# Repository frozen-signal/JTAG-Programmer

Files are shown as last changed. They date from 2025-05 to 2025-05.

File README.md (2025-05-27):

# Description

A Kicad project for a JTAG Programmer. Compatible with Lattice Diamond Programmer, Radiant Programmer and iCEcube2.

# How to use

## One-time setup

Once assembled, a one-time setup need to be done:
1. Download and install [FT_Prog from FTDI](https://ftdichip.com/utilities/#ft_prog)
1. Connect the JTAG-Programmer to your PC with a USB cable.
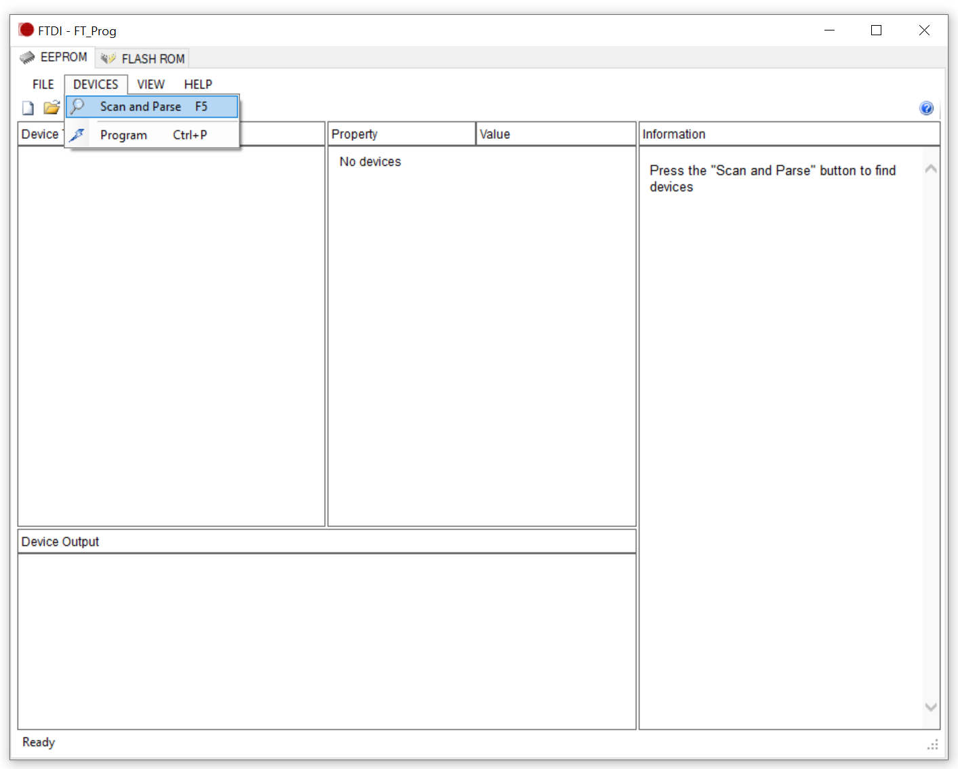
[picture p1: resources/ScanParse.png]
1. Do a scan: DEVICE > Scan and parse.<br />
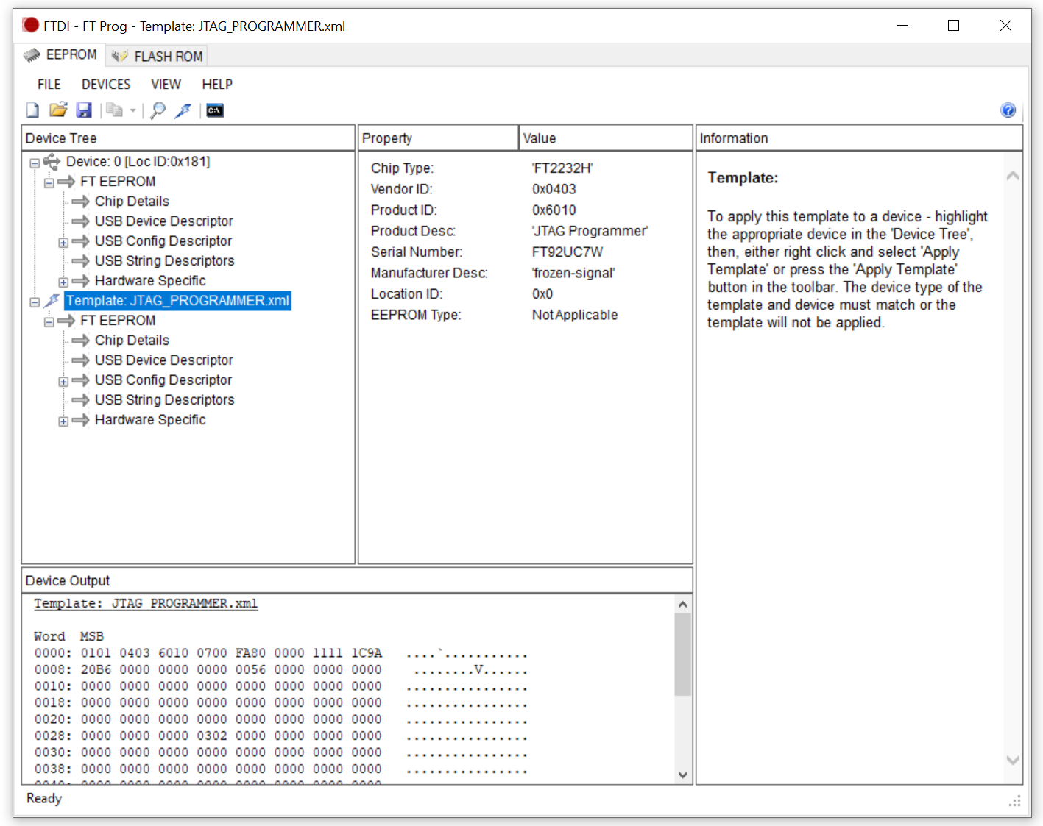
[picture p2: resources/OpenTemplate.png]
1. Go to FILE > Open Template and select "JTAG_PROGRAMMER.xml".<br />
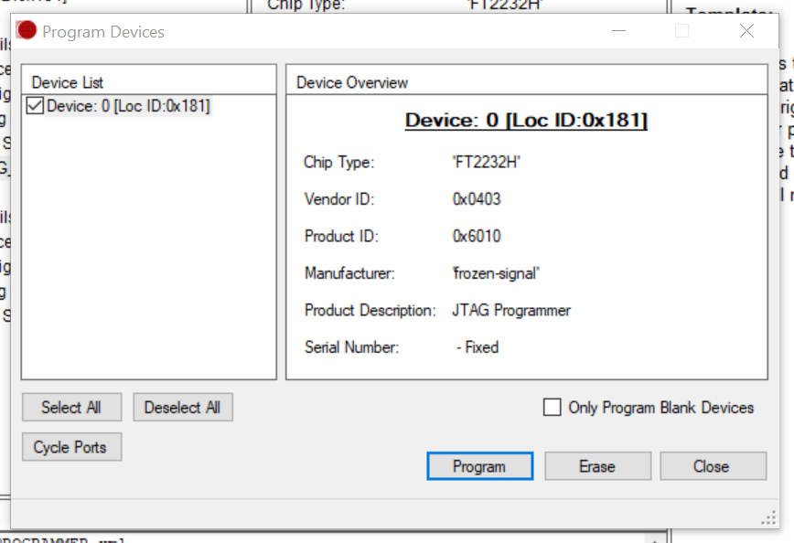
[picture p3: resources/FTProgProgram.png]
1. Go to DEVICE > Program, and click "Erase". Once completed, click "Program".<br />
1. Make sure the JTAG-Programmer has been correctly programmed by quitting FT_Prog and re-opening it, then doing a scan again. Check that the template has been applied to the JTAG-Programmer ("Product Desc" should be "JTAG Program").

## Example of Programming a MACHXO2 FPGA with Lattice Diamond Programmer

This shows an example of how the JTAG-Programmer can be used to program a FPGA. This example suppose you already have installed the Lattice Diamond Programmer (As standalone or as part of the [Lattice Diamond Toolchain](https://www.latticesemi.com/Products/DesignSoftwareAndIP/FPGAandLDS/LatticeDiamond)
1. Make sure the JTAG-Programmer is connected to the PC.
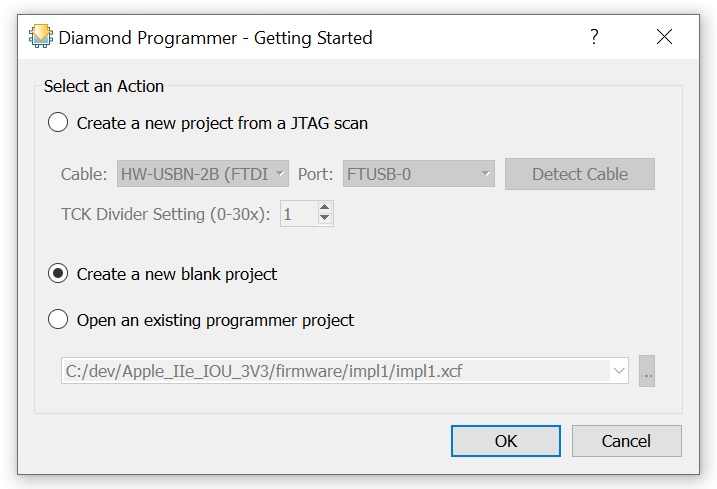
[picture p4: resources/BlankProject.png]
1. Run the Lattice Diamond Programmer, select "Create a new blank project" is selected, and click "OK".<br />
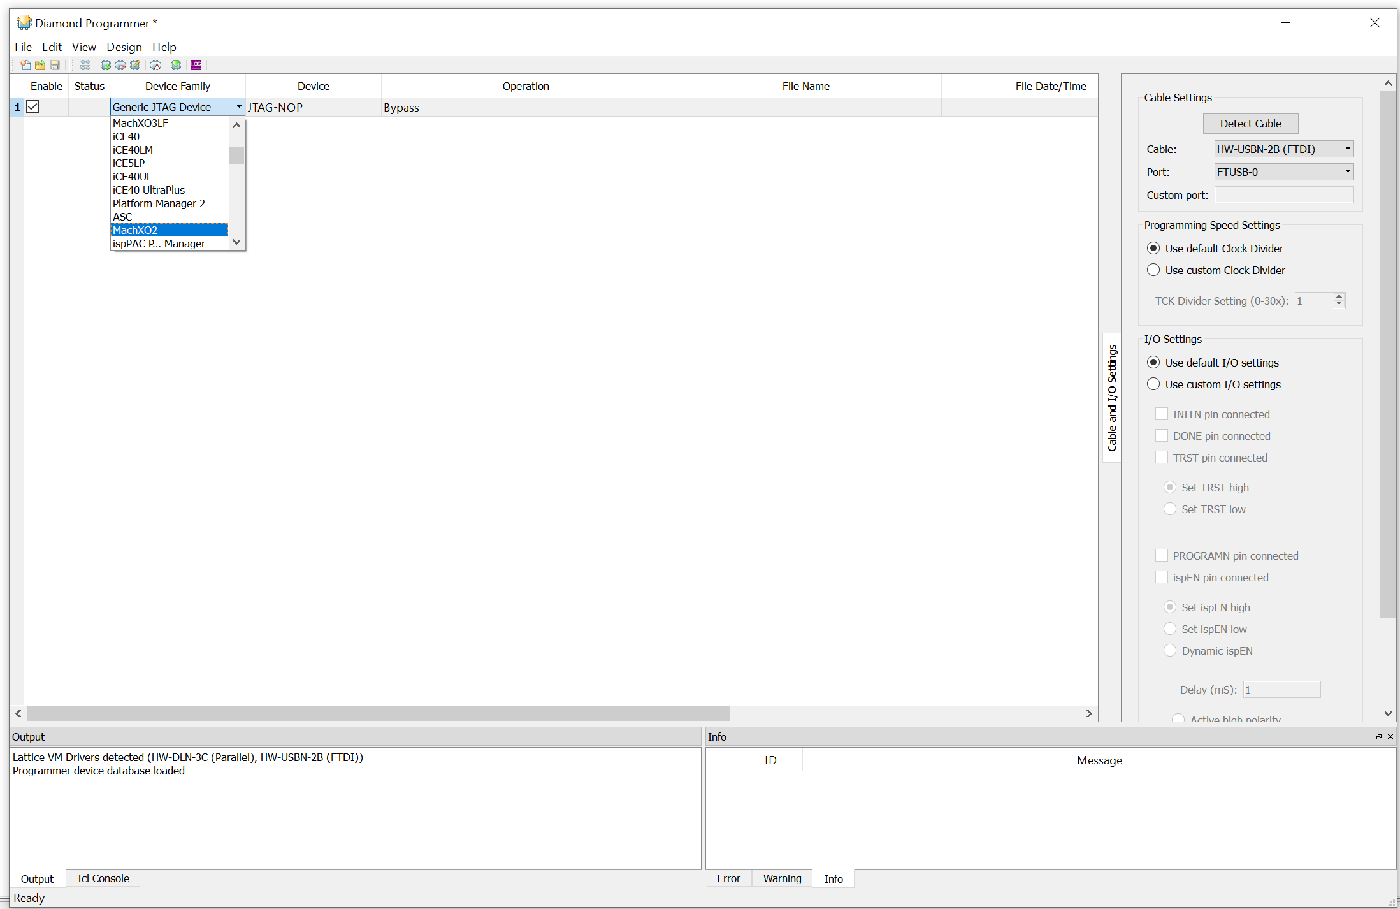
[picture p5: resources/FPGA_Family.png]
1. Click on the "Generic JTAG Device" under Device Family, and select the FPGA family.<br />
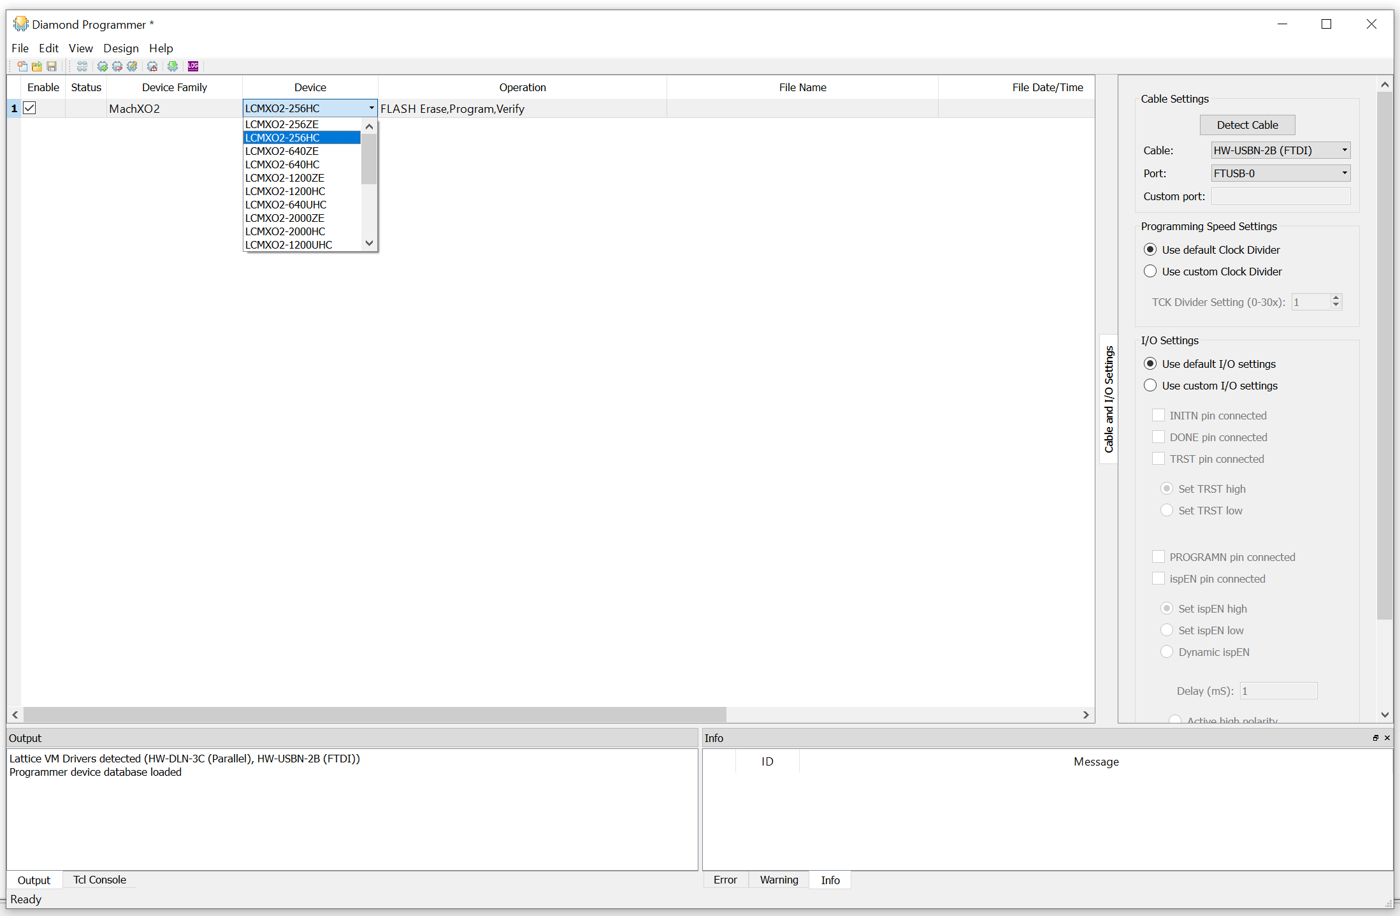
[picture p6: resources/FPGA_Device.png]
1. Click on the element under "Device" and select the correct device.<br />
1. Make sure the Operation is "Flash Erase,Program,Verify".
1. Under File Name, select the programming file. In our case, it's the generated JEDEC file (*.jed).
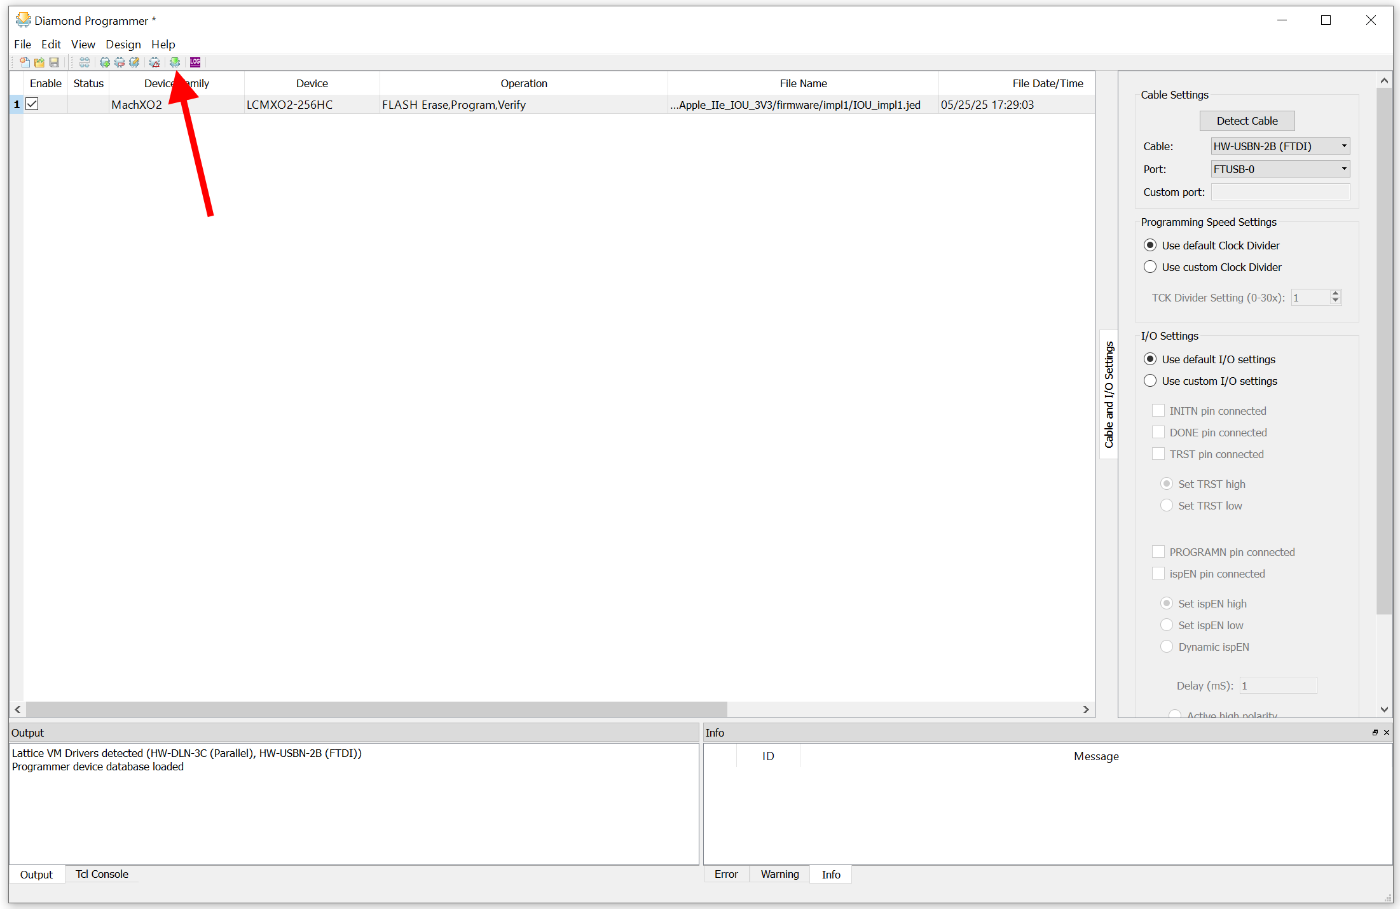
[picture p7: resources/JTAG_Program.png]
1. Connect the JTAG cable to the device and click "Program".<br />
1. Once Diamond Programmer finishes, your FPGA should now be programmed.

# An overview of the JTAG-Programmer
(TODO: Add a description of the pins)

<a align="center">
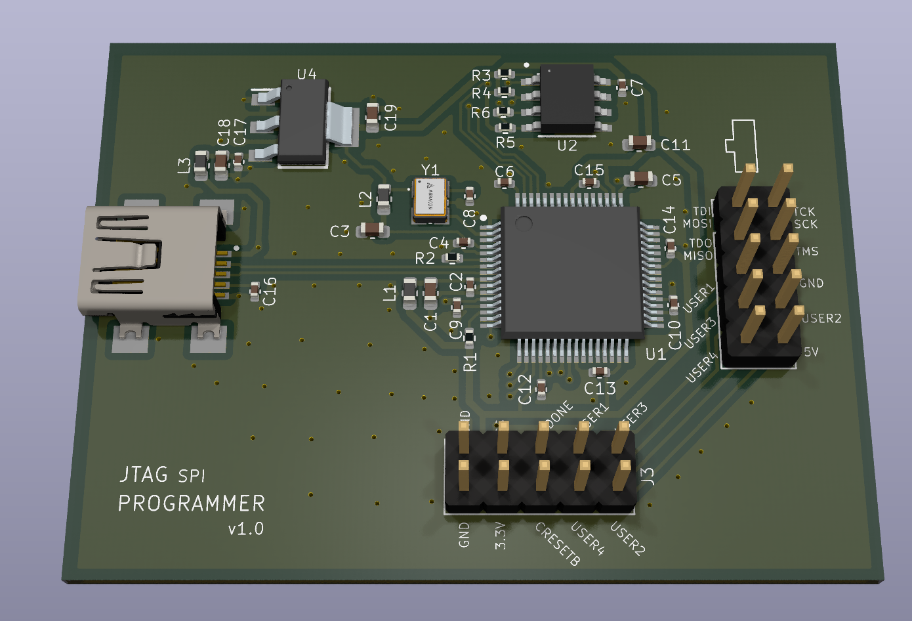
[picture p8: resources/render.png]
    
</a>
<p><i>A rendering of the programmer</i></p>

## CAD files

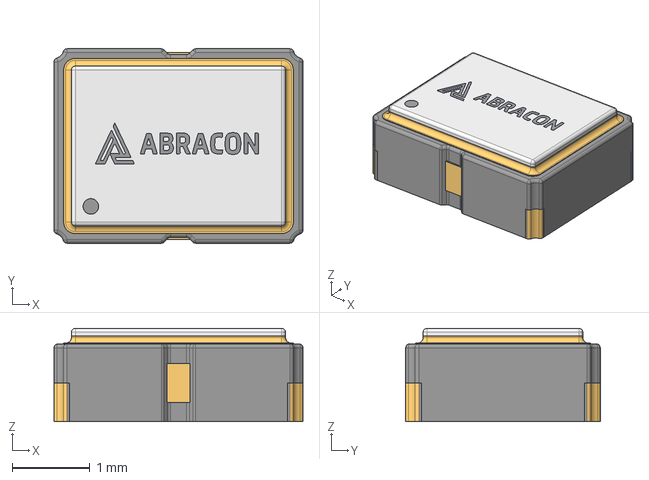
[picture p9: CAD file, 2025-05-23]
3D_Models/ASE-12.000MHZ-LC-T.step
3.20 x 2.50 x 1.20 mm
ASE-25.000MHZ-LR-T
Abracon New Logo

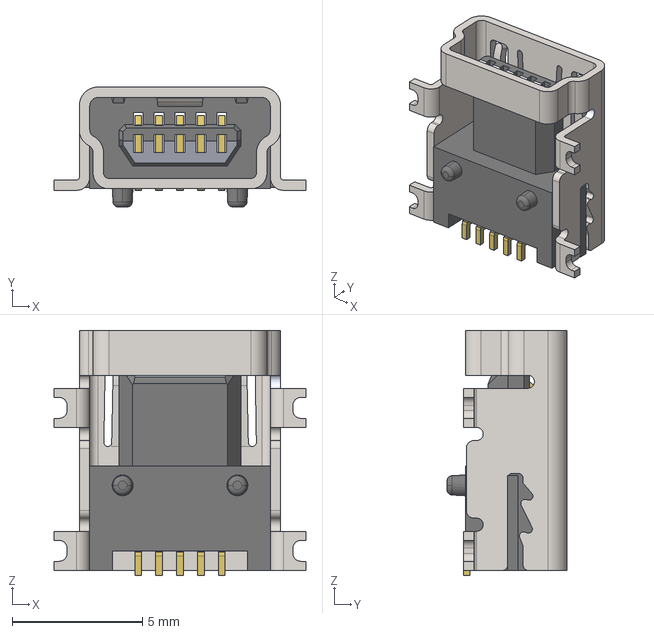
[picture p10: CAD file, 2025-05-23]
3D_Models/UJ2-MBH-1-SMT-TR.step
9.66 x 4.60 x 9.40 mm

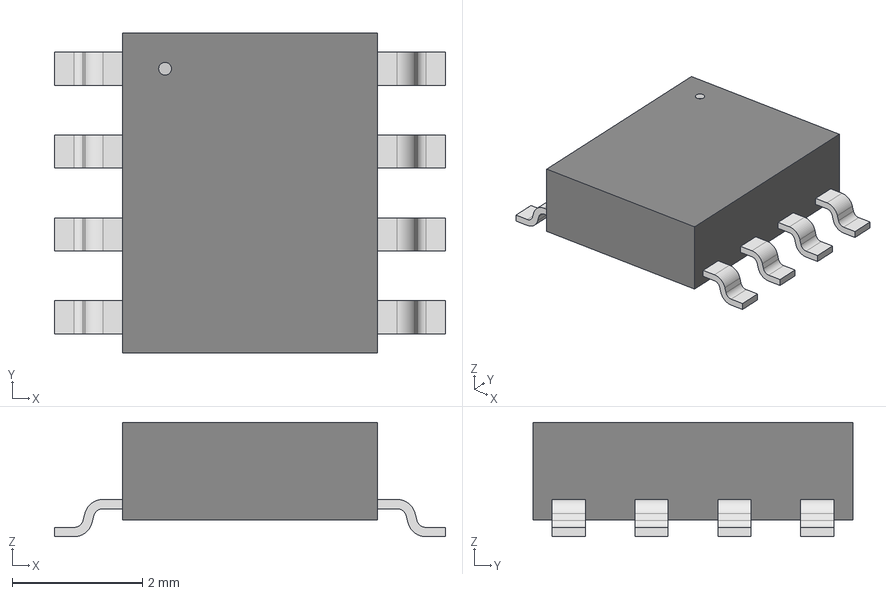
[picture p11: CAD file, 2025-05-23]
3D_Models/93LC56C_I_SN.step
5.99 x 4.90 x 1.75 mm

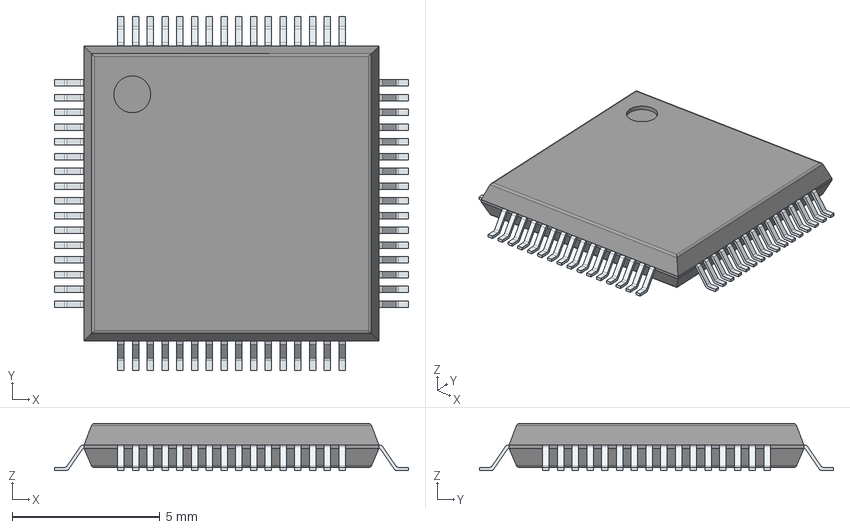
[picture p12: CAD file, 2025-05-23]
3D_Models/FT2232HL-REEL.step
12.0 x 12.0 x 1.60 mm
PinsArrayLR
PinsArrayTB

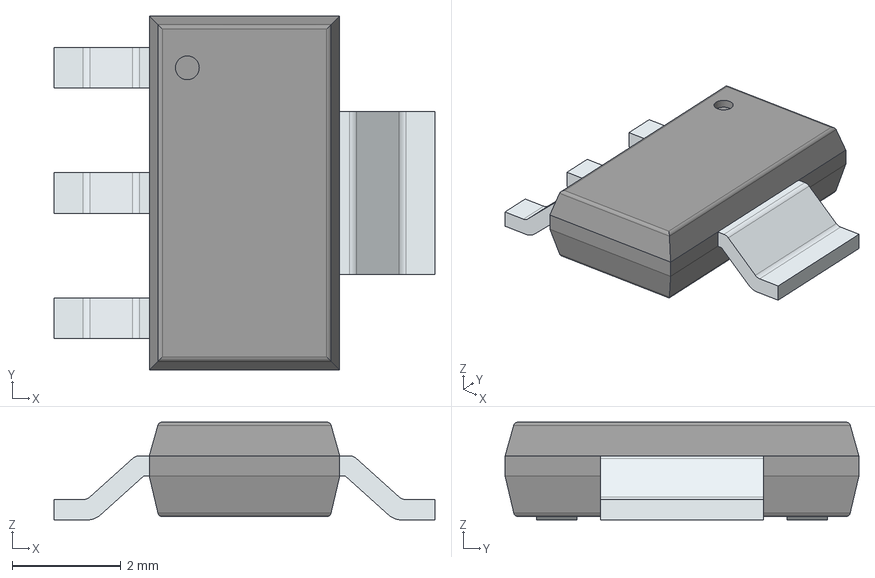
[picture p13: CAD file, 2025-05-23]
3D_Models/TLV1117LV33DCYR.step
7.00 x 6.50 x 1.80 mm
PinsArrayL
FilletPinR

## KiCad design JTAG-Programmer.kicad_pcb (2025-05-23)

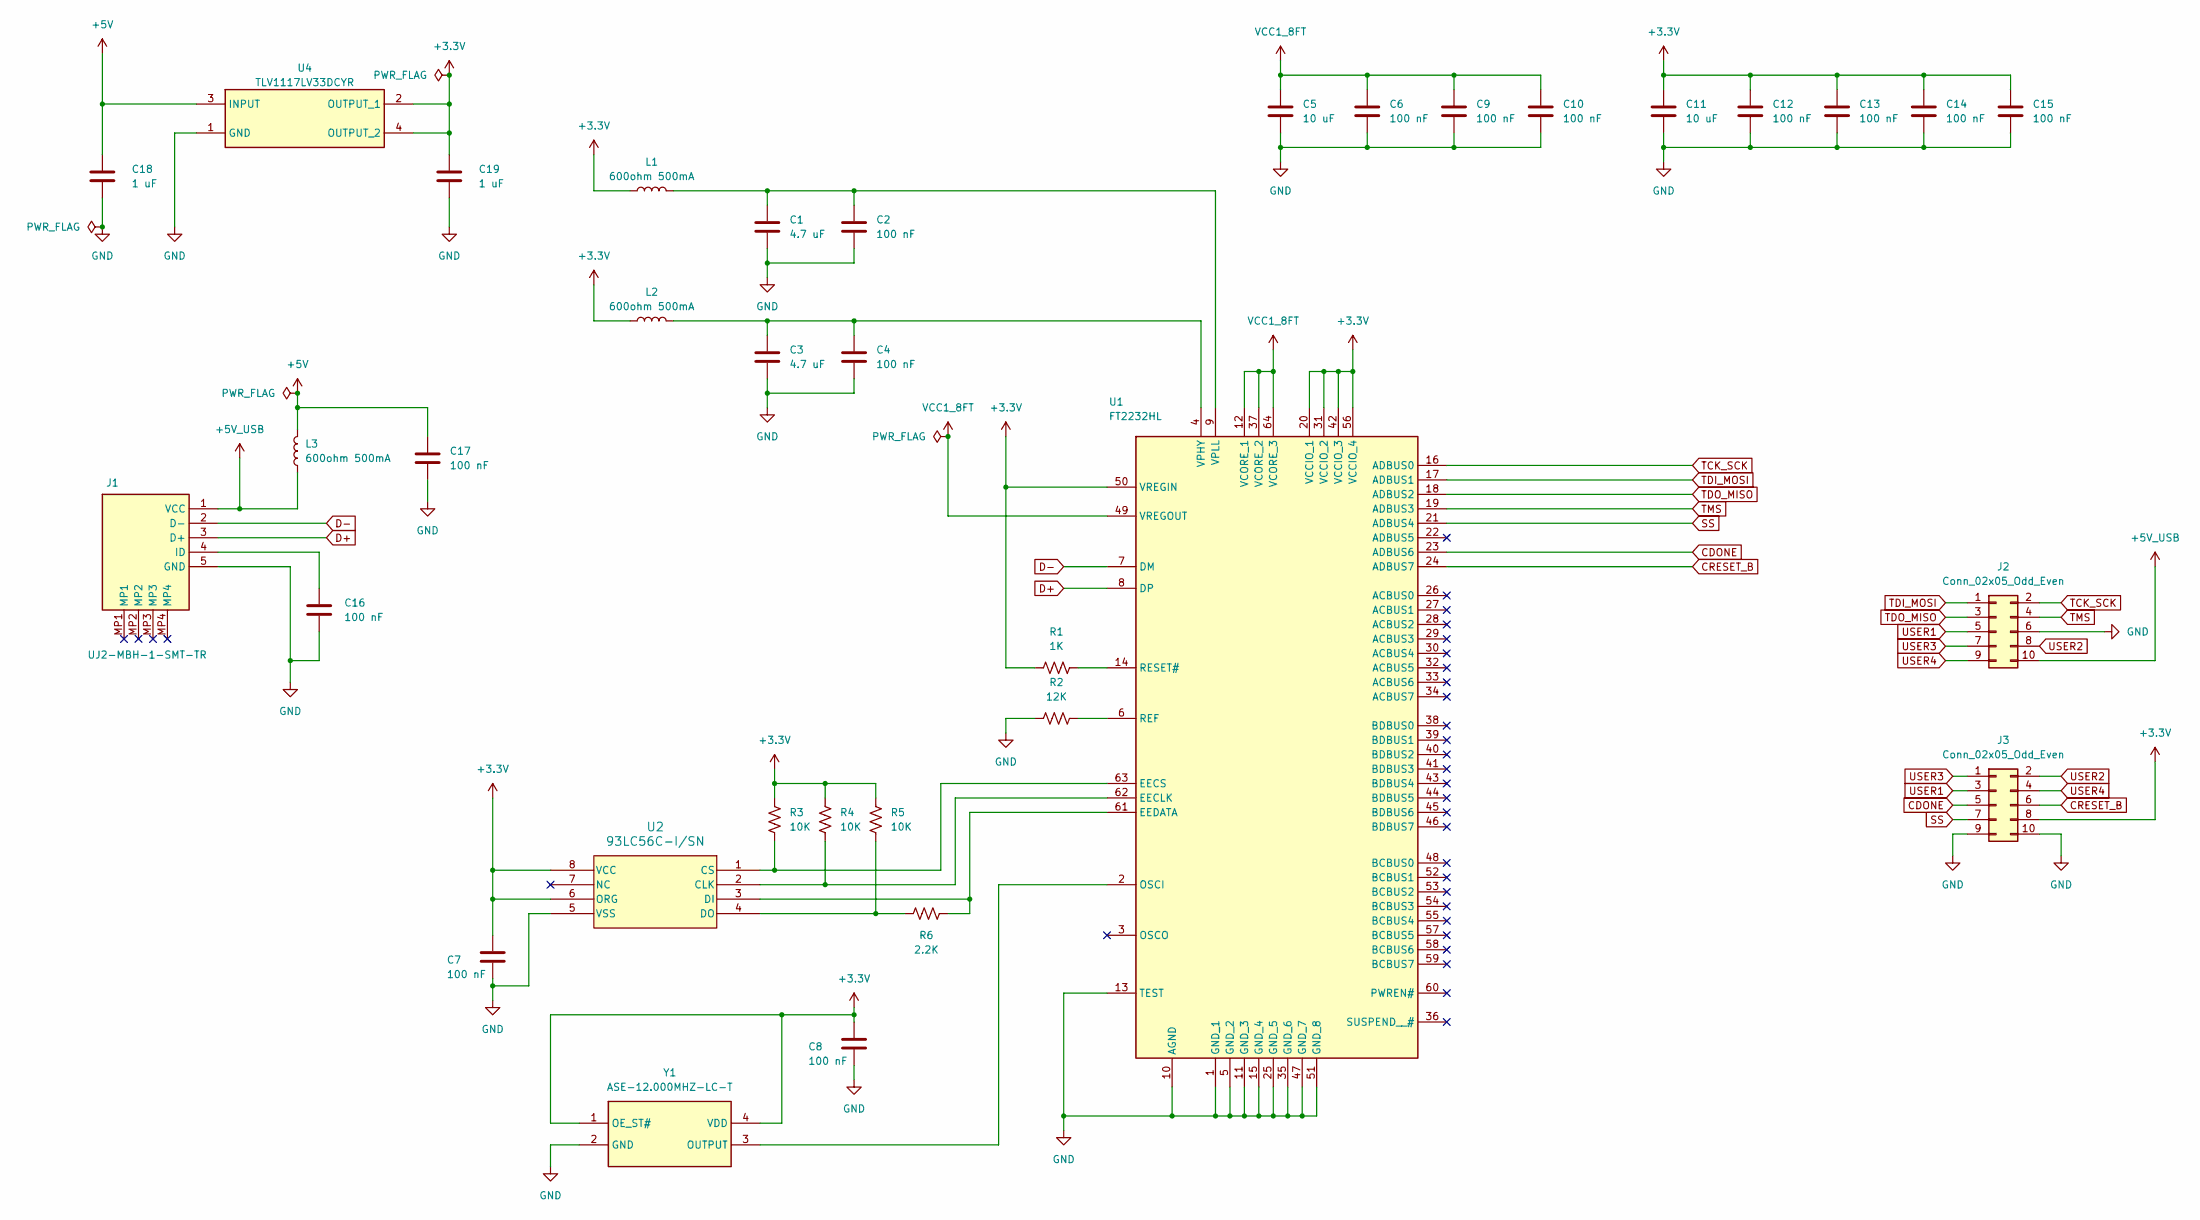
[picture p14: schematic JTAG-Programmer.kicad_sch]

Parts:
C1, C3: 4.7 uF; C_0603_1608Metric
C2, C4, C6, C7, C8, C9, C10, C12, C13, C14, C15, C16, C17: 100 nF; C_0402_1005Metric
C5, C11: 10 uF; C_0603_1608Metric
C18, C19: 1 uF; C_0603_1608Metric
J1: UJ2-MBH-1-SMT-TR; UJ2MBH1SMTTR; Mouser Part Number 490-UJ2-MBH-1-SMT
J2, J3: Conn_02x05_Odd_Even; PinHeader_2x05_P2.54mm_Vertical
L1, L2, L3: 600ohm 500mA; L_0603_1608Metric
R1: 1K; R_0402_1005Metric
R2: 12K; R_0402_1005Metric
R3, R4, R5: 10K; R_0402_1005Metric
R6: 2.2K; R_0402_1005Metric
U1: FT2232HL; QFP50P1200X1200X160-64N; Mouser Part Number 895-FT2232HL
U2: 93LC56C-I/SN; SOIC8-N_MC_MCH
U4: TLV1117LV33DCYR; SOT230P700X180-4N; Mouser Part Number 595-TLV1117LV33DCYR
Y1: ASE-12.000MHZ-LC-T; ASE24576MHZLCT; Mouser Part Number 815-ASE12.000MHZLCT

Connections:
+3.3V: C7.1, C8.1, C11.1, C12.1, C13.1, C14.1, C15.1, C19.1, J3.8, L1.1, L2.1, R1.1, R3.2, R4.2, R5.2, U1.20 (VCCIO_1), U1.31 (VCCIO_2), U1.42 (VCCIO_3), U1.50 (VREGIN), U1.56 (VCCIO_4), U2.6 (ORG), U2.8 (VCC), U4.2 (OUTPUT_1), U4.4 (OUTPUT_2), Y1.1 (OE_ST#), Y1.4 (VDD)
+5V: C17.1, C18.1, L3.2, U4.3 (INPUT)
+5V_USB: J1.1 (VCC), J2.10, L3.1
CDONE: J3.5, U1.23 (ADBUS6)
CRESET_B: J3.6, U1.24 (ADBUS7)
D+: J1.3 (D+), U1.8 (DP)
D-: J1.2 (D-), U1.7 (DM)
GND: C1.2, C2.2, C3.2, C4.2, C5.2, C6.2, C7.2, C8.2, C9.2, C10.2, C11.2, C12.2, C13.2, C14.2, C15.2, C16.2, C17.2, C18.2, C19.2, J1.5 (GND), J2.6, J3.9, J3.10, R2.1, U1.1 (GND_1), U1.5 (GND_2), U1.10 (AGND), U1.11 (GND_3), U1.13 (TEST), U1.15 (GND_4), U1.25 (GND_5), U1.35 (GND_6), U1.47 (GND_7), U1.51 (GND_8), U2.5 (VSS), U4.1 (GND), Y1.2 (GND)
unnamed: C16.1, J1.4 (ID)
unnamed: R4.1, U1.62 (EECLK), U2.2 (CLK)
unnamed: R3.1, U1.63 (EECS), U2.1 (CS)
unnamed: R6.1, U1.61 (EEDATA), U2.3 (DI)
unnamed: U1.2 (OSCI), Y1.3 (OUTPUT)
unnamed: R2.2, U1.6 (REF)
unnamed: R1.2, U1.14 (RESET#)
unnamed: C3.1, C4.1, L2.2, U1.4 (VPHY)
unnamed: C1.1, C2.1, L1.2, U1.9 (VPLL)
unnamed: R5.1, R6.2, U2.4 (DO)
SS: J3.7, U1.21 (ADBUS4)
TCK_SCK: J2.2, U1.16 (ADBUS0)
TDI_MOSI: J2.1, U1.17 (ADBUS1)
TDO_MISO: J2.3, U1.18 (ADBUS2)
TMS: J2.4, U1.19 (ADBUS3)
USER1: J2.5, J3.3
USER2: J2.8, J3.2
USER3: J2.7, J3.1
USER4: J2.9, J3.4
VCC1_8FT: C5.1, C6.1, C9.1, C10.1, U1.12 (VCORE_1), U1.37 (VCORE_2), U1.49 (VREGOUT), U1.64 (VCORE_3)

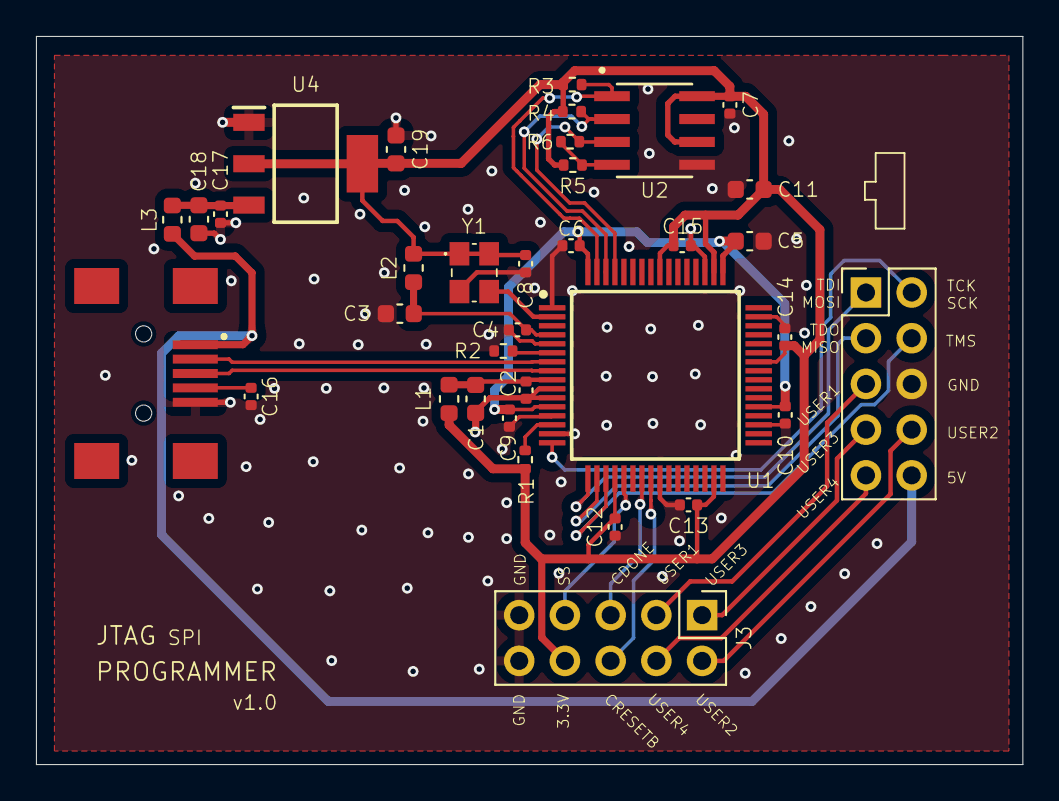
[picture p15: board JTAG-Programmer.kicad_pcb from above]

Board: 2 copper layers, 54.8 x 40.5 mm, 35 parts (0 on the bottom side), 28 nets.
